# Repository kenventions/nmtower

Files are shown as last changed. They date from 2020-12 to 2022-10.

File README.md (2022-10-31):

# nmtower

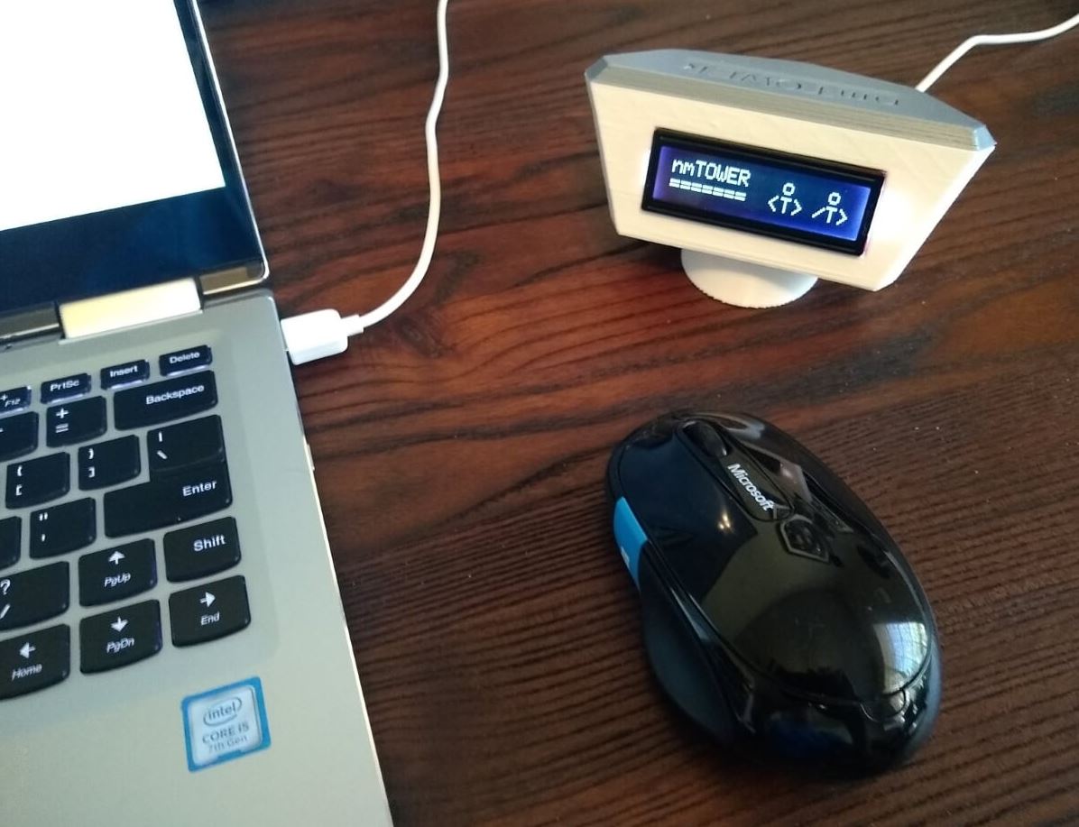
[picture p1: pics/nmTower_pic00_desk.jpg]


nmTOWER is an Arduino project that originally used ADSBexchange.com data to answer the question "What's near my TOWER?". That ADSBx API is no longer available for free so I'm working on a program update that uses your own ADS-B receiver as the source for nearby aircraft.
nmTOWER displays data about the nearest aircraft, refreshing the data approx every 30 seconds.

The nmTOWER requires three electronic components that will cost approx $60 shipped - NO SOLDERING required!

Browse the nmTOWER pics to see the three different pages of aircraft data displayed. If you're interested in building your own nmTOWER, keep reading.

WHAT YOU'LL NEED
- ADS-B receiver that's on the same network as your nmTower project  
- SparkFun Thing Plus - ESP32 WROOM, WRL-15663
- SparkFun 16x2 SerLCD - RGB Text (Qwiic), LCD-16397
- Qwiic Cable - 100mm or 200mm, PRT-14427 or PRT-14428
- Micro-USB to USB cable

OPTIONAL
- nmTOWER Housing, 3D-printed using 0.35mm layers with 20% infill and supports ON (build plate only), approx 5hrs
- nmTOWER Roof, 3D-printed using 0.35mm layers with 20% infill and NO supports, approx 1hr
- 2 small screws to secure the ESP32 board (2mm x 7mm tall)

BUILD INSTRUCTIONS
- Connect the LCD display to the ESP32 using the Qwiic cable
- Use a micro-USB cable to connect the ESP32 to your PC
- Open the Arduino IDE, under TOOLS, select the "Adafruit ESP32 Feather" board, then select the detected PORT
- Open the nmTower_Program_V1 file and update the USER VARIABLES including your WiFi info and ADS-B box IP address
- Click the UPLOAD arrow to save your changes and upload the program to your ESP32
- Once the ESP32 reboots and the nmTOWER starts displaying nearby aircraft data, you can close the Arduino IDE
- You can re-locate the nmTOWER - it will auto-reboot when it's plugged back in 

TIPS FOR HOUSING INSTALLATION
- Remove the three support posts in the nmTOWER window by clipping them at the base of each post
- The LCD display needs to be carefully installed to avoid snapping the two tension arms
- First make sure the LCD metal housing is centered in the window opening
- Slowly work the LCD display down, keeping the display level/square in the window opening
- There is a resistor on the back right side of the display - the tension arm will need help getting over that resistor
- Once installed, the LCD will have some slight movemment - that's normal
- Install the ESP32 between the guide posts and secure with the two small screws
- Connect the micro-USB to boot up your nmTOWER!

If you'd like to create a tower replica of one of your favorite airport towers, the Tinkercad nmTOWER housing design is available here - https://www.tinkercad.com/things/ggPbq1SoOyi . Just ungroup and delete/modify any of the objects to create your new tower, then export the STL for printing. Please upload pics of your replicas in the /tower_replicas folder.

Thanks to all the great Flightaware ADS-B forum members who helped me get started with my first ADS-B receiver and DIY antenna about 18 months ago!
It's my favorite ADS-B forum!

regards,
kenf3

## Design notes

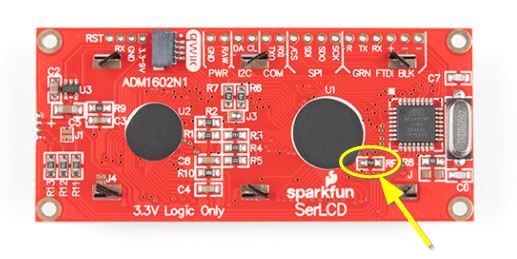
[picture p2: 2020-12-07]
pics/nmTower_pic12_LCDresistor.jpg

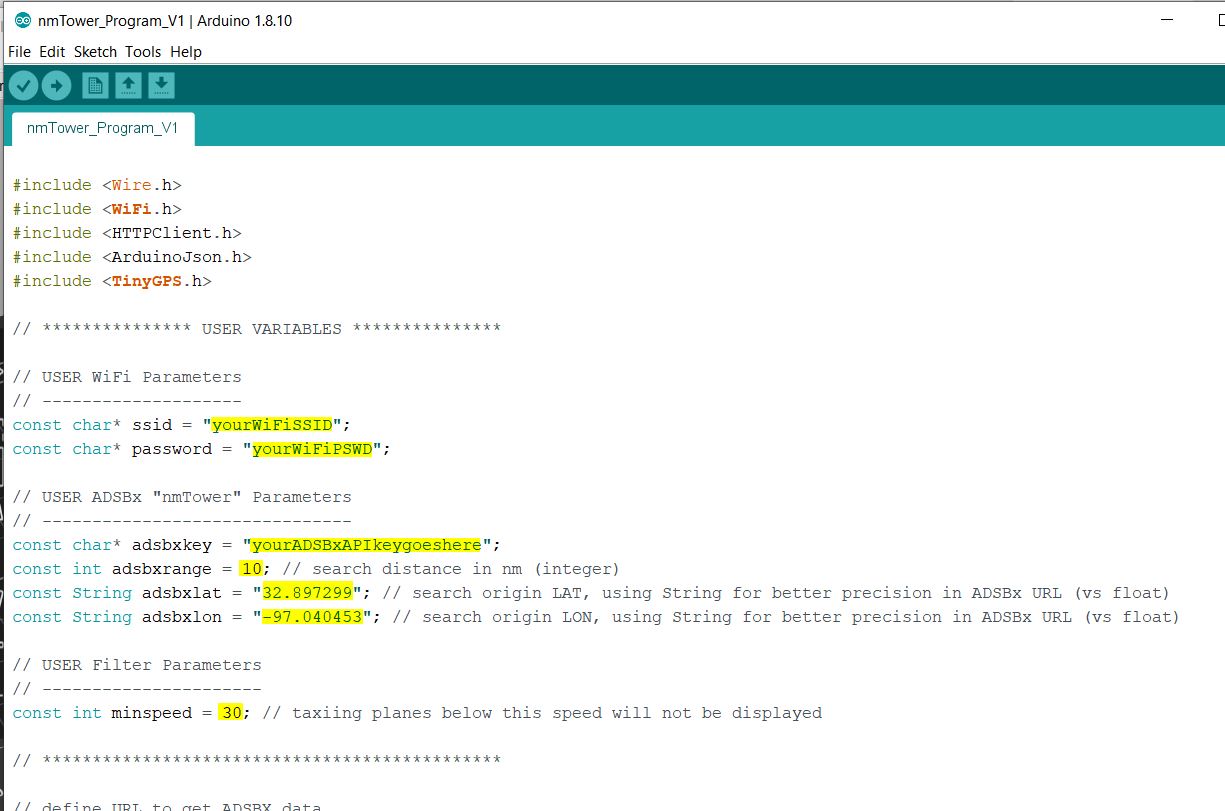
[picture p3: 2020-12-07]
pics/nmTower_pic13_UserVariables.jpg

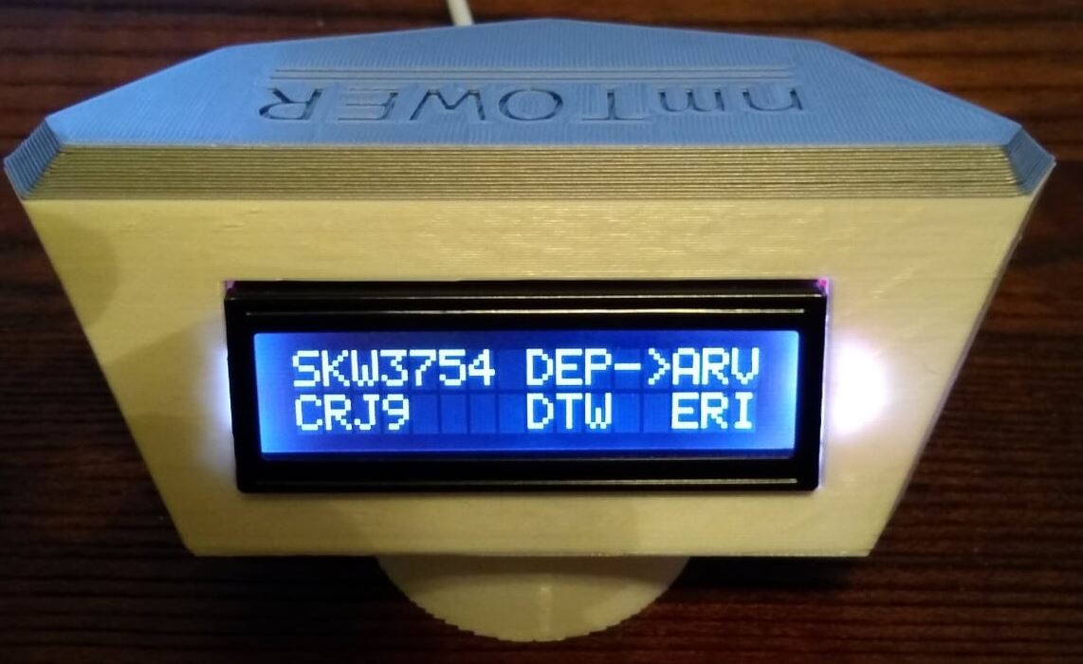
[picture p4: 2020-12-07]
pics/nmTower_pic06_aircraftpage3.jpg

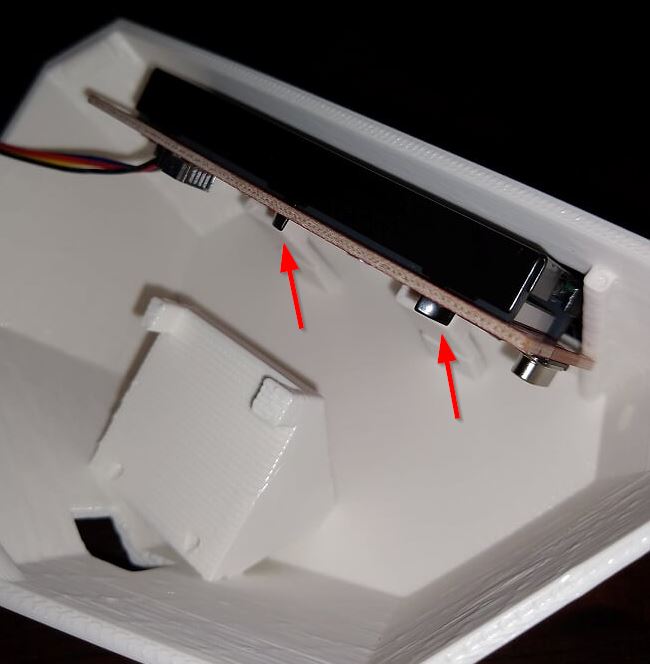
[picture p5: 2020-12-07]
pics/nmTower_pic11_LCDback.jpg

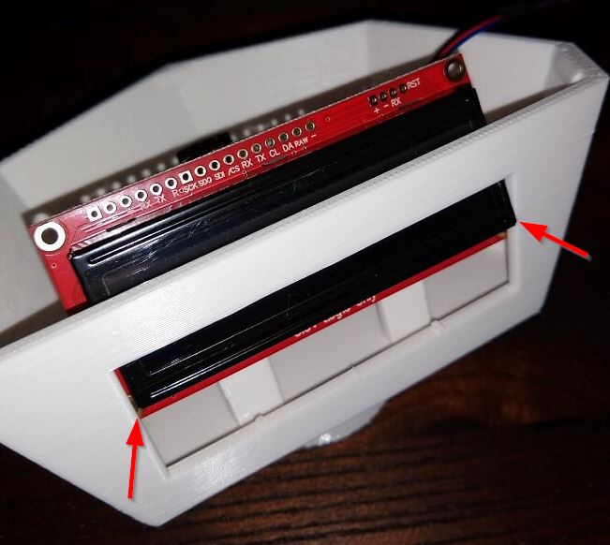
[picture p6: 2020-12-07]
pics/nmTower_pic10_LCDfront.jpg

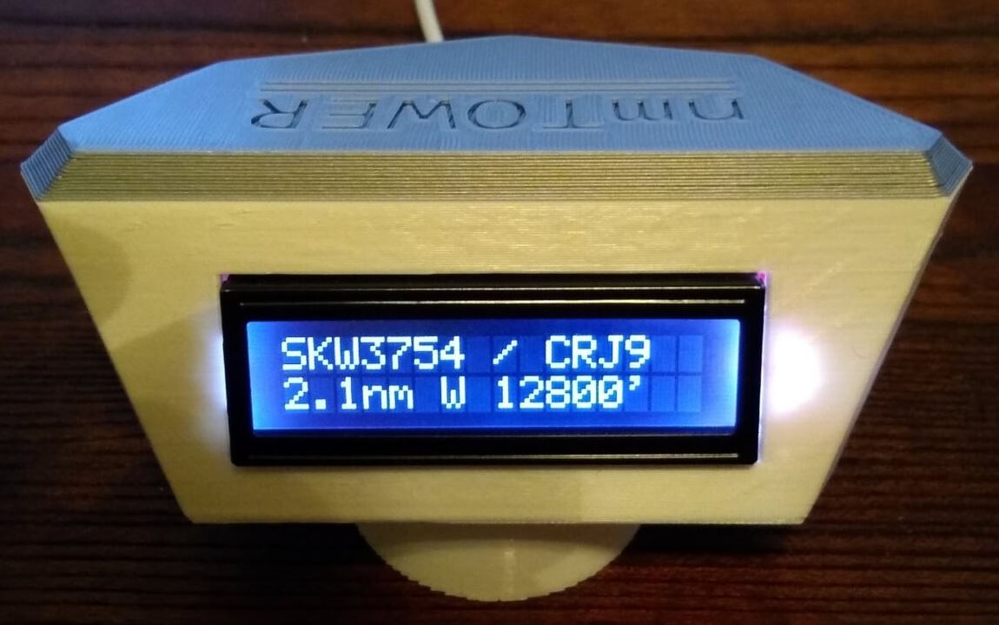
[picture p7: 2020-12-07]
pics/nmTower_pic04_aircraftpage1.jpg

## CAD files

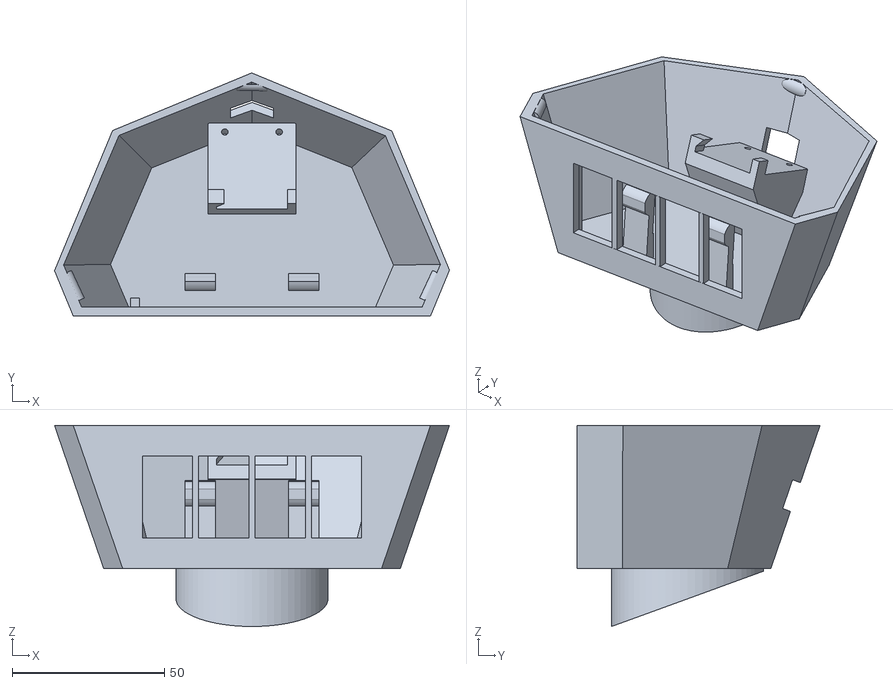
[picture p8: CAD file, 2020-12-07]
nmTower_STL_Housing.stl
129.8 x 79.9 x 66.1

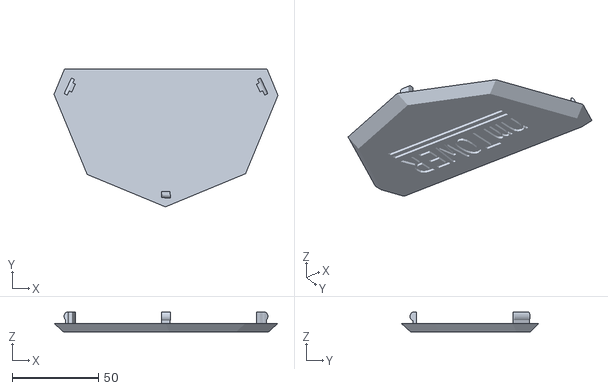
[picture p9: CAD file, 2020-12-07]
nmTower_STL_Roof.stl
130.0 x 79.9 x 11.5

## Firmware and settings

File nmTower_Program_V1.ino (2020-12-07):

#include <Wire.h>
#include <WiFi.h>
#include <HTTPClient.h>
#include <ArduinoJson.h>
#include <TinyGPS.h>

// *************** USER VARIABLES ***************

// USER WiFi Parameters
// --------------------
const char* ssid = "yourWiFiSSID";
const char* password = "yourWiFiPSWD";

// USER ADSBx "nmTower" Parameters
// -------------------------------
const char* adsbxkey = "yourADSBxAPIkeygoeshere";
const int adsbxrange = 10; // search distance in nm (integer)
const String adsbxlat = "32.897299"; // search origin LAT, using String for better precision in ADSBx URL (vs float)
const String adsbxlon = "-97.040453"; // search origin LON, using String for better precision in ADSBx URL (vs float)

// USER Filter Parameters
// ----------------------
const int minspeed = 30; // taxiing planes below this speed will not be displayed 

// **********************************************

// define URL to get ADSBX data
String adsbxurl = "https://adsbexchange.com/api/aircraft/json/lat/" + adsbxlat + "/lon/" + adsbxlon + "/dist/" + String(adsbxrange);

// initialize LCD display
#include <SerLCD.h> //Click here to get the library: http://librarymanager/All#SparkFun_SerLCD
SerLCD lcd; // Initialize the library with default I2C address 0x72

// initialize JSON settings
const size_t capacity = 60000;
DynamicJsonDocument doc(capacity);

// function for Near My Tower (nmTower) graphic
void tower() {
  lcd.clear(); 
  lcd.print("nmTOWER   o   o");
  lcd.setCursor(0, 1);
  lcd.print("=======  <T> /T>");
  delay(3000);
}

// function for RADAR animation
void radar() {
  lcd.setCursor(0, 0);
  lcd.print("]           -<-'");
  lcd.setCursor(0, 1);
  lcd.print("I               ");
  delay(1000);
  lcd.setCursor(1, 0);lcd.print(")");
  for (int i = 0; i <= 9; i++) {
    lcd.setCursor(2+i, 0);lcd.print(")");
    lcd.setCursor(1+i, 0);lcd.print(" ");
  }
  for (int i = 0; i <= 9; i++) {
    lcd.setCursor(10-i, 0);lcd.print("(");
    lcd.setCursor(11-i, 0);lcd.print(" ");
  }
  lcd.setCursor(0, 0);
  lcd.print("]           -<-'");
  delay(250);
}  

// program intro (executed once)
void setup() {
  // LCD prep 
  Wire.begin();
  lcd.begin(Wire); //Set up the LCD for I2C communication
  lcd.setBacklight(200, 170, 255); //Set backlight to bright white
  lcd.setContrast(10); //Set contrast. Lower to 0 for higher contrast.
  delay(1000);

  tower();

  lcd.clear(); 
  lcd.print("LAT: ");lcd.print(adsbxlat);
  lcd.setCursor(0, 1);
  lcd.print("LON: "); lcd.print(adsbxlon);
  delay(3000);

  // start serial comms & WiFi
  Serial.begin(115200);
  WiFi.begin(ssid, password);
 
  while (WiFi.status() != WL_CONNECTED) {
    delay(500);
    lcd.clear();
    lcd.setCursor(0, 1);
    lcd.print("WiFi search ...");
    delay(3000);
    lcd.clear();
    lcd.print("ID=" + String(ssid));
    lcd.setCursor(0, 1);
    lcd.print("PW=" + String(password));
    delay(3000);
  }
  lcd.clear();
Serial.println("setup complete");
}

// main program loop
void loop() {

    tower();

  // Check WiFi Status
  if (WiFi.status() == WL_CONNECTED) {
    HTTPClient http;  //Object of class HTTPClient

    radar();

    // Submit adsbx api request
    http.begin(adsbxurl);
    http.addHeader("api-auth", adsbxkey);
    int httpCode = http.GET();
    //Check the returning code                                                                  
    if (httpCode > 0) {
      // Get the request response payload
      String payload = http.getString();
      http.end();   //Close connection
      
      // Serial.println(payload);
      
      deserializeJson(doc, payload);
      JsonArray currList = doc["ac"]; // Get a reference to the array

      Serial.println("json complete");

      // display plane count and search distance
      lcd.setCursor(0, 1);
      lcd.print("Planes: " + String(currList.size()) + " <" +String(adsbxrange) +"nm");
      delay(3000);

      if(currList.size()!=0) {

        // Print plane details in serial monitor for debugging
        // for (JsonObject currPlane : currList) {
          //Serial.print(" call- "); Serial.print(currPlane["call"].as<String>());
          //Serial.print(", type: "); Serial.print(currPlane["type"].as<String>());
          //Serial.print(", alt: "); Serial.print(currPlane["alt"].as<int>());
          //Serial.print(", spd: "); Serial.print(currPlane["spd"].as<int>());
          //Serial.print(", trak: "); Serial.print(currPlane["trak"].as<int>());
          //Serial.print(", dst: "); Serial.println(currPlane["dst"].as<float>());
          //  Serial.print(", from: "); Serial.print(currPlane["from"].as<String>());
          //  Serial.print(", to: "); Serial.print(currPlane["to"].as<String>());
        // }
        
        //Serial.println(adsbxurl);
        //Serial.println(currList.size());

        // find nearest plane
        int np = 0;
        float tempdst = 0;
    
        if (currList.size()>1) {
          for (int i = 0; i < currList.size()-1; i++) {
            if (currList[np]["spd"].as<float>()>float(minspeed)) {
              if ((currList[np]["dst"].as<float>() > currList[i+1]["dst"].as<float>()) 
                && currList[i+1]["spd"].as<float>()>float(minspeed)) {
                np = i+1;
              }
            } else {np++; i++;};   
            Serial.print(np); Serial.print(" "); Serial.print(currList[np]["call"].as<String>());
            Serial.print(" "); Serial.print(currList[np]["dst"].as<float>());
            Serial.print(" "); Serial.println(currList[np]["spd"].as<float>());
          }
        } 

        // determine bearing to plane
        String npBear="N";
        float targetBear = TinyGPS::course_to(adsbxlat.toFloat(),adsbxlon.toFloat(),currList[np]["lat"],currList[np]["lon"]);
        if (targetBear>337.5 || targetBear<=22.5) {npBear="N";}
        if (targetBear>22.5 && targetBear<=67.5) {npBear="NE";}
        if (targetBear>67.5 && targetBear<=112.5) {npBear="E";}
        if (targetBear>112.5 && targetBear<=157.5) {npBear="SE";}
        if (targetBear>157.5 && targetBear<=202.5) {npBear="S";}
        if (targetBear>202.5 && targetBear<=247.5) {npBear="SW";}
        if (targetBear>247.5 && targetBear<=292.5) {npBear="W";}
        if (targetBear>292.5 && targetBear<=337.5) {npBear="NW";}
 
        // display plane details, page 1
        if (currList[np]["call"]=="") {currList[np]["call"]=currList[np]["icao"];}
        if (currList[np]["type"]=="") {currList[np]["type"]="no type";}
        lcd.clear();
        lcd.print(currList[np]["call"].as<String>());lcd.print(" / ");lcd.print(currList[np]["type"].as<String>());
        lcd.setCursor(0,1);
        lcd.print(currList[np]["dst"].as<float>(),1);lcd.print("nm ");lcd.print(npBear);lcd.print(" ");
        lcd.print(currList[np]["alt"].as<int>());lcd.print("'");
        Serial.println("page1 complete");
        delay(7000);

        // determine heading of plane
        String npHdg="N";
        if (currList[np]["trak"].as<float>()>337.5 || currList[np]["trak"].as<float>()<=22.5) {npHdg="N";}
        if (currList[np]["trak"].as<float>()>22.5 && currList[np]["trak"].as<float>()<=67.5) {npHdg="NE";}
        if (currList[np]["trak"].as<float>()>67.5 && currList[np]["trak"].as<float>()<=112.5) {npHdg="E";}
        if (currList[np]["trak"].as<float>()>112.5 && currList[np]["trak"].as<float>()<=157.5) {npHdg="SE";}
        if (currList[np]["trak"].as<float>()>157.5 && currList[np]["trak"].as<float>()<=202.5) {npHdg="S";}
        if (currList[np]["trak"].as<float>()>202.5 && currList[np]["trak"].as<float>()<=247.5) {npHdg="SW";}
        if (currList[np]["trak"].as<float>()>247.5 && currList[np]["trak"].as<float>()<=292.5) {npHdg="W";}
        if (currList[np]["trak"].as<float>()>292.5 && currList[np]["trak"].as<float>()<=337.5) {npHdg="NW";}

        // display plane details, page 2
        lcd.clear();
        lcd.print(currList[np]["call"].as<String>());
        lcd.setCursor(8,0);lcd.print("HDG= ");lcd.print(npHdg);
        lcd.setCursor(0,1); lcd.print("As ");lcd.print(currList[np]["spd"].as<float>(),0);
        lcd.setCursor(8,1);lcd.print("Vs ");lcd.print(currList[np]["vsi"].as<int>());
        Serial.println("page2 complete");
        delay(7000);

        // display plane details, page 3
        String depID = currList[np]["from"].as<String>();depID.remove(3);
        String arvID = currList[np]["to"].as<String>();arvID.remove(3);
        if (depID == "nul") {depID=" -"; arvID=" -";}
        lcd.clear();
        lcd.print(currList[np]["call"].as<String>());lcd.setCursor(8,0);lcd.print("DEP->ARV");
        lcd.setCursor(0,1);lcd.print(currList[np]["type"].as<String>());
        lcd.setCursor(8,1);lcd.print(depID);lcd.setCursor(13,1);lcd.print(arvID);
        Serial.println("page3 complete");
        delay(7000);

      } else { // no planes in search area
        Serial.println("no planes");
        delay(30000);  
      }
            
    } else { // no ADSBX response

      lcd.clear();
      lcd.setCursor(0, 1);
      lcd.print("No ADSBx reply!");
      Serial.println("no ADSBx reply");
      delay(2000);
    }
    
  } else { // no WIFI connection

    lcd.clear();
    lcd.setCursor(0, 1);
    lcd.print("WIFI lost ...");
    Serial.println("no WiFi");
    delay(2000);  
  }
Serial.println("loop complete");
Serial.println("***"); 
 
} // end of main program loop
